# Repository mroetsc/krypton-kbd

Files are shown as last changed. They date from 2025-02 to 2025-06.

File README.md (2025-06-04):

# Krypton-KBD

Ergonmic split keyboard created with [ergogen](https://github.com/ergogen/ergogen).

Named after the noble gas [krypton](https://en.wikipedia.org/wiki/Krypton).

## Features
* Completely wireless with support for wired
* One rotary encoder per half
* Num row
* Ergonomic, easily reachable thumb cluster, also ideal for larger hands
* 3D-printed case (open and closed versions) and switchplate
* Support for [ZMK Studio](https://zmk.dev/docs/features/studio), allowing keymap changes without reflashing
* Support for nice!view displays

## Images
keyboard

# Build instructions
The build instructions can be found [here](https://github.com/mroetsc/krypton-kbd/blob/main/docs/build_instructions.md).

## Keymap
The default keymap is for Colemak-DH. It can easily be changed using [ZMK Studio](https://zmk.dev/docs/features/studio).
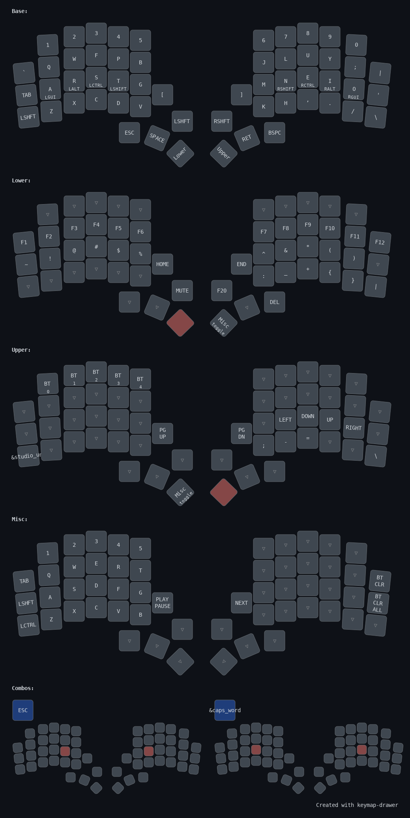
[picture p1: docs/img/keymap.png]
Keymap Drawing


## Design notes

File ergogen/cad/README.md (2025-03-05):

# CAD Model sources
## Rotary encoder
https://grabcad.com/library/ec11-rotary-encoder-with-switch-1 (modified colors)

## Encoder knob
https://grabcad.com/library/rotary-encoder-with-knop-1 (modified to only have knob)

## JST connector
https://grabcad.com/library/jst-ph-2-00mm-connector-set-1

## Kali hotswap socket
https://grabcad.com/library/kailh-hotswap-mx-1

## Nice!Nano
https://grabcad.com/library/nice-nano-v2-board-1 (modified colors)

## MX keycaps
https://grabcad.com/library/cherry-mx-keycaps-1 (cut out and modified color)

## MX switch
https://grabcad.com/library/kailh-polia-switch-cherry-mx-compatible-1 (modified colors)

## Nice!View
https://grabcad.com/library/nice-view-oled-1

## Power switch
https://tech.alpsalpine.com/e/products/detail/SSSS811101/ (modified colors)

## Reset switch
https://grabcad.com/library/panasonic_evqpuj_evqpua-1

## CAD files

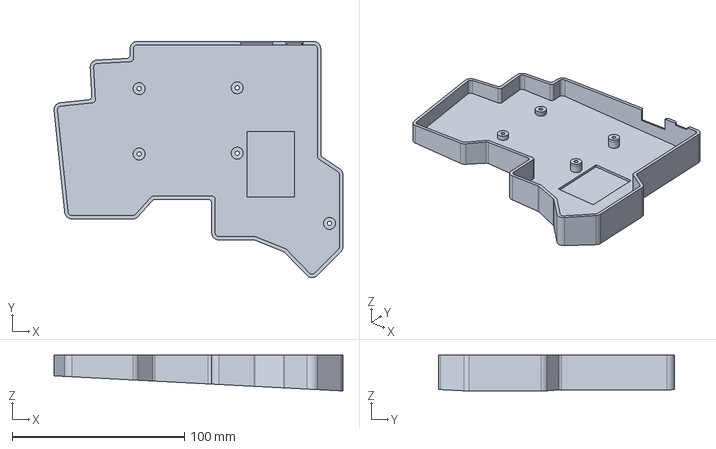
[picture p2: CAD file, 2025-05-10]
case/closed_case.FCStd
167.9 x 137.2 x 20.9 mm

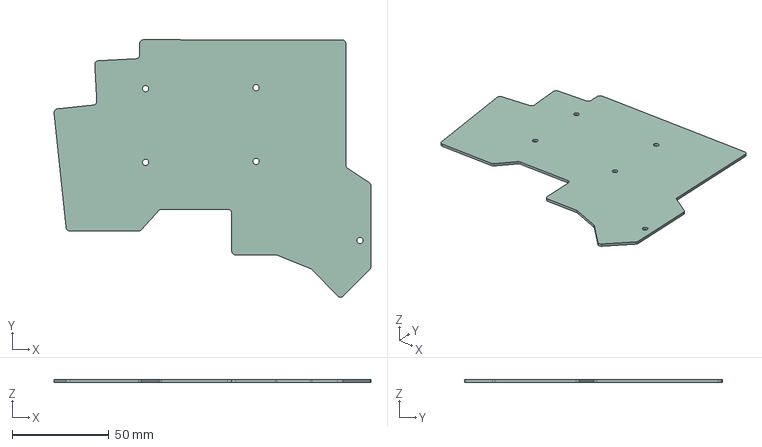
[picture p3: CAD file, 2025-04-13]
case/parts/pcb_left.step
163.5 x 132.8 x 1.51 mm

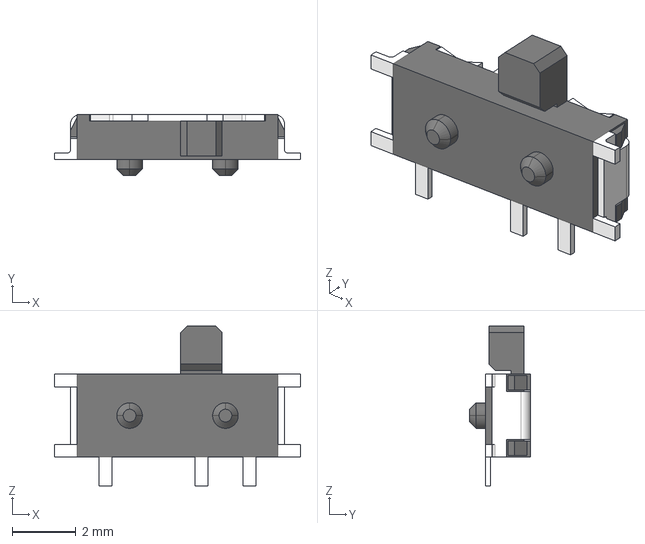
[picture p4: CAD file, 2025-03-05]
ergogen/cad/power_switch.stp
7.70 x 1.90 x 5.00 mm

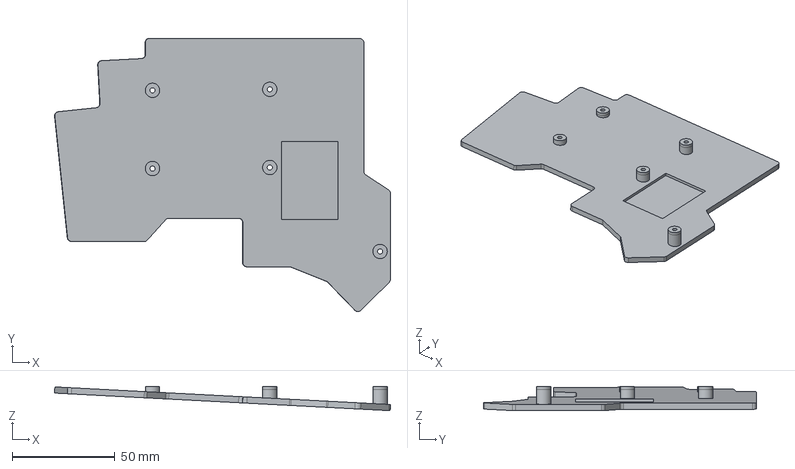
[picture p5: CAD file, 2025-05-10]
case/exports/open_case-left.step
163.3 x 132.8 x 11.8 mm

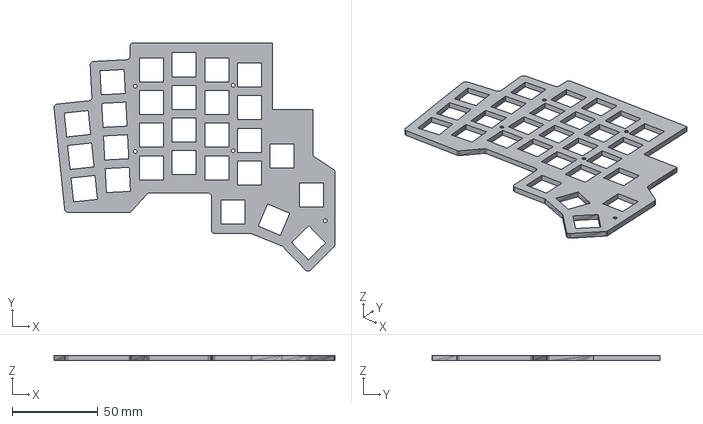
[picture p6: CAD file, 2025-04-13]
case/parts/switchplate_left.step
163.5 x 132.8 x 3.00 mm

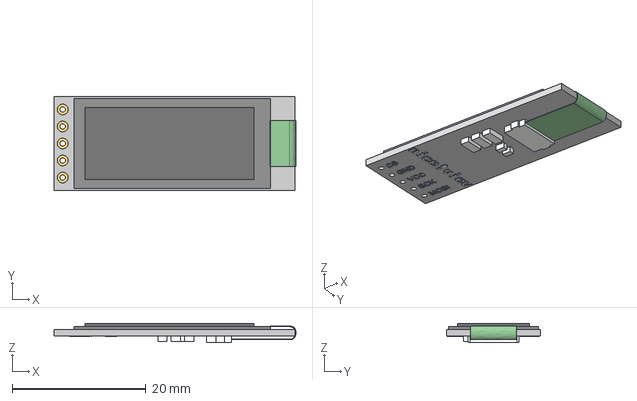
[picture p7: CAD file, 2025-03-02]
ergogen/cad/nice_view.step
36.1 x 14.0 x 2.90 mm

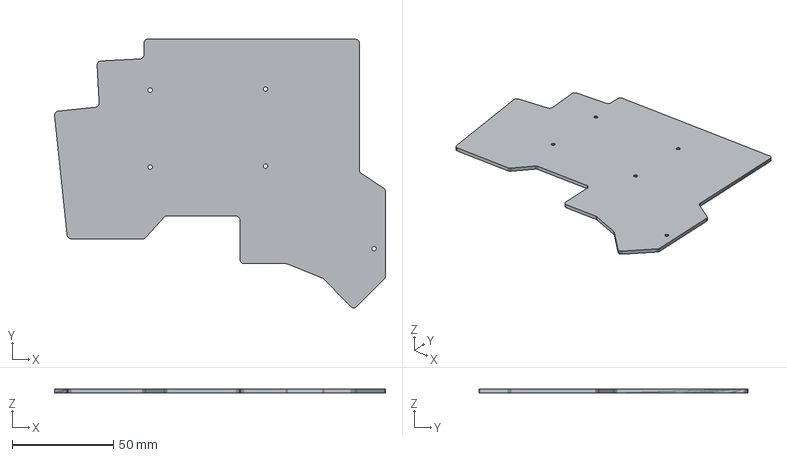
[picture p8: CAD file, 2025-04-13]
case/parts/bottom_left.step
163.5 x 132.8 x 2.00 mm

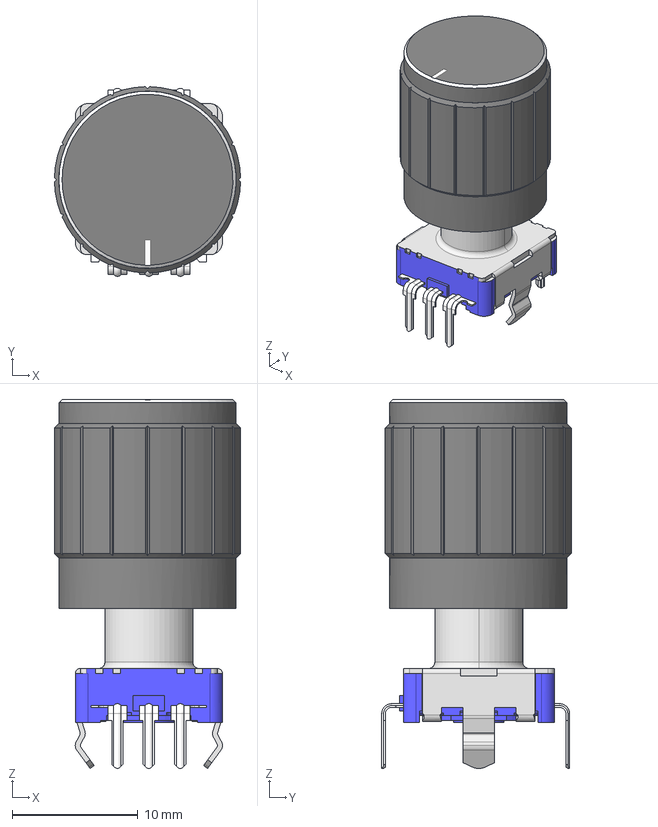
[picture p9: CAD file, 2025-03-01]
ergogen/cad/encoder_with_knob.step
14.8 x 15.1 x 29.3 mm
ÃÃ½ÃÂªÂ±Ã ÃÃ«ÃÃ·EC11E-05SW
Rotary Encoder - KY-040 v023

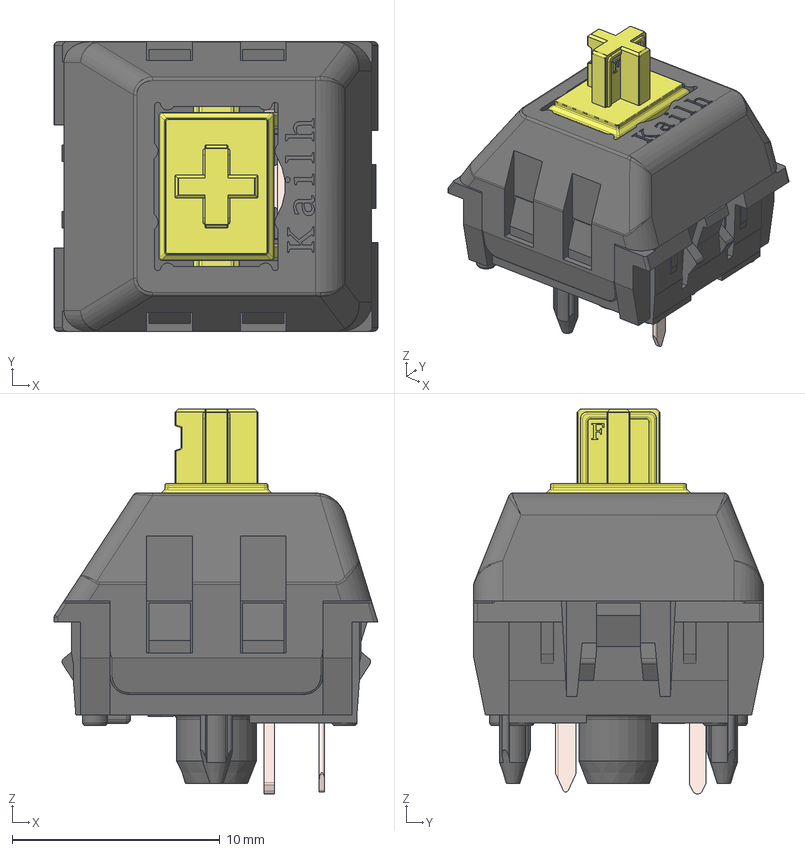
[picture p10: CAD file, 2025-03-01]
ergogen/cad/mx_switch.step
15.6 x 13.9 x 18.5 mm
Housing
ThickContact
SpringContact
Stem
Lid

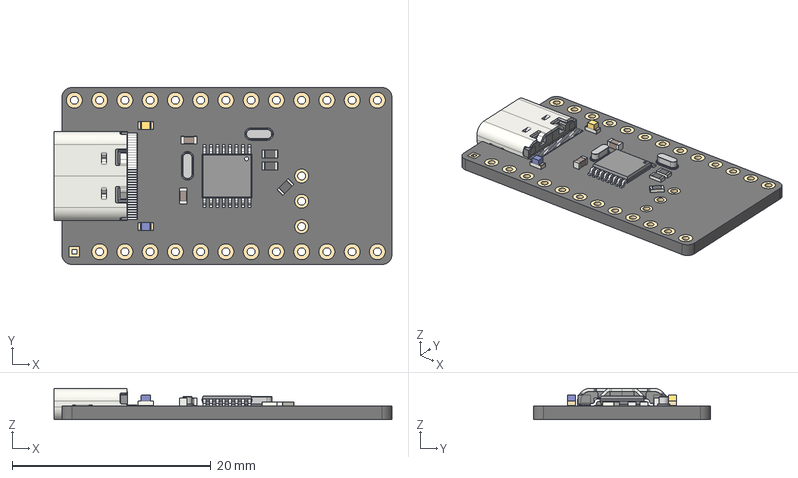
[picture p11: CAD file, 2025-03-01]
ergogen/cad/mcu_nice_nano.step
34.0 x 17.8 x 3.16 mm
nice!nano v1.0
nice!nano v1.001
nice!nano v1.002
nice!nano v1.003
nice!nano v1.004
nice!nano v1.005
nice!nano v1.006
nice!nano v1.007
nice!nano v1.008
nice!nano v1.009
nice!nano v1.010
nice!nano v1.011
nice!nano v1.012
nice!nano v1.013
nice!nano v1.014
nice!nano v1.015
nice!nano v1.016
nice!nano v1.017
nice!nano v1.018
nice!nano v1.019
nice!nano v1.020
nice!nano v1.021
nice!nano v1.022
nice!nano v1.023
nice!nano v1.024
nice!nano v1.025
nice!nano v1.026
nice!nano v1.027
nice!nano v1.028
nice!nano v1.029
nice!nano v1.030
nice!nano v1.031
nice!nano v1.032
nice!nano v1.033
nice!nano v1.034
nice!nano v1.035
nice!nano v1.036
nice!nano v1.037
nice!nano v1.038
nice!nano v1.039
nice!nano v1.040
nice!nano v1.041
nice!nano v1.042
nice!nano v1.043
nice!nano v1.044
nice!nano v1.045
nice!nano v1.046
nice!nano v1.047
nice!nano v1.048
nice!nano v1.049
nice!nano v1.050
nice!nano v1.051
nice!nano v1.052
nice!nano v1.053
nice!nano v1.054
nice!nano v1.055
nice!nano v1.056
nice!nano v1.057
nice!nano v1.058
nice!nano v1.059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

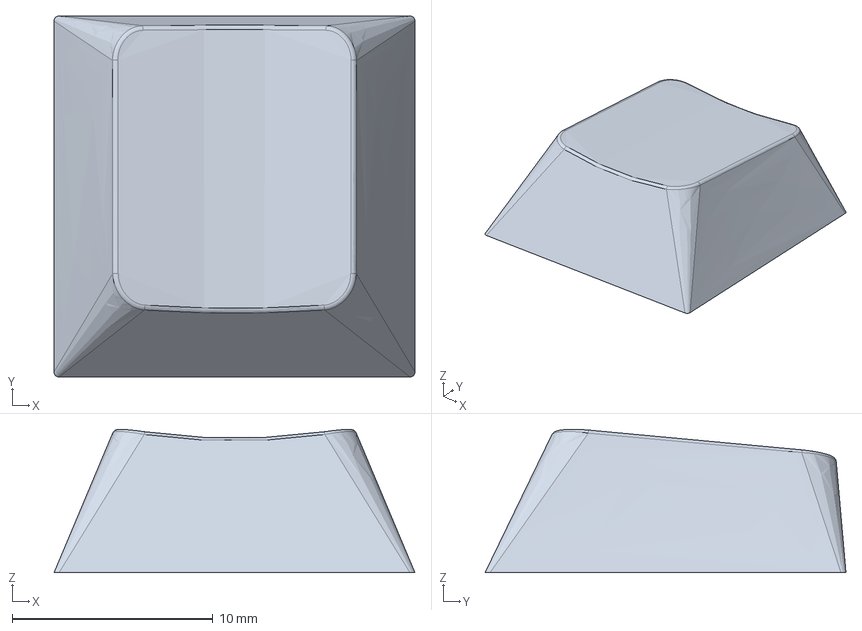
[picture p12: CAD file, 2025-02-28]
ergogen/cad/mx_keycap.step
18.0 x 18.0 x 7.15 mm

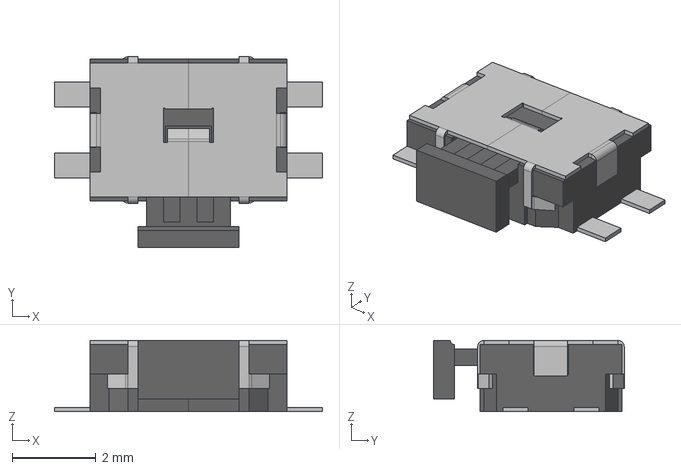
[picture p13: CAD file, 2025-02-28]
ergogen/cad/reset_switch.step
6.40 x 4.55 x 1.70 mm

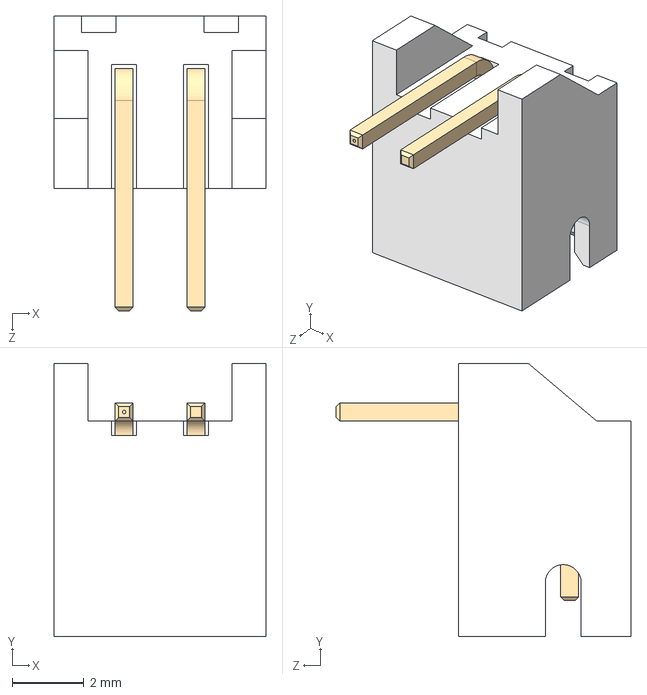
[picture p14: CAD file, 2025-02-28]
ergogen/cad/jst_connector.step
5.90 x 7.60 x 8.20 mm

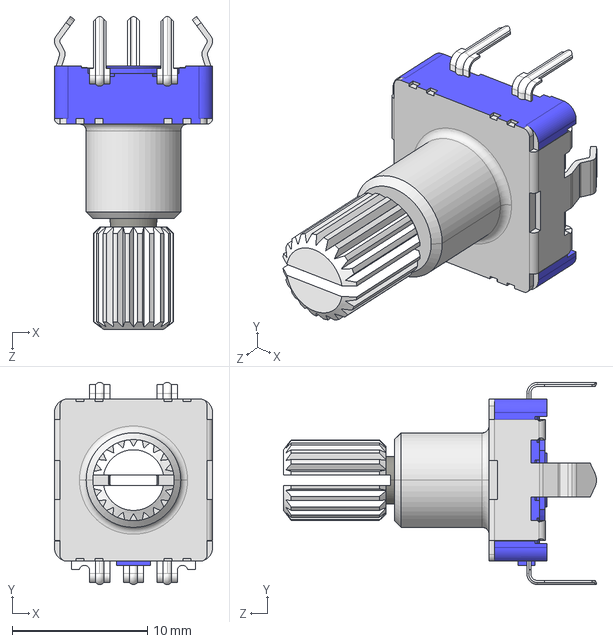
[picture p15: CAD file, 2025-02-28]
ergogen/cad/encoder.step
11.7 x 15.0 x 23.2 mm

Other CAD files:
case/exports/closed_case-left.step
case/open_case.FCStd
ergogen/cad/kali_hotswap.step
case/exports/switchplate-left.stl

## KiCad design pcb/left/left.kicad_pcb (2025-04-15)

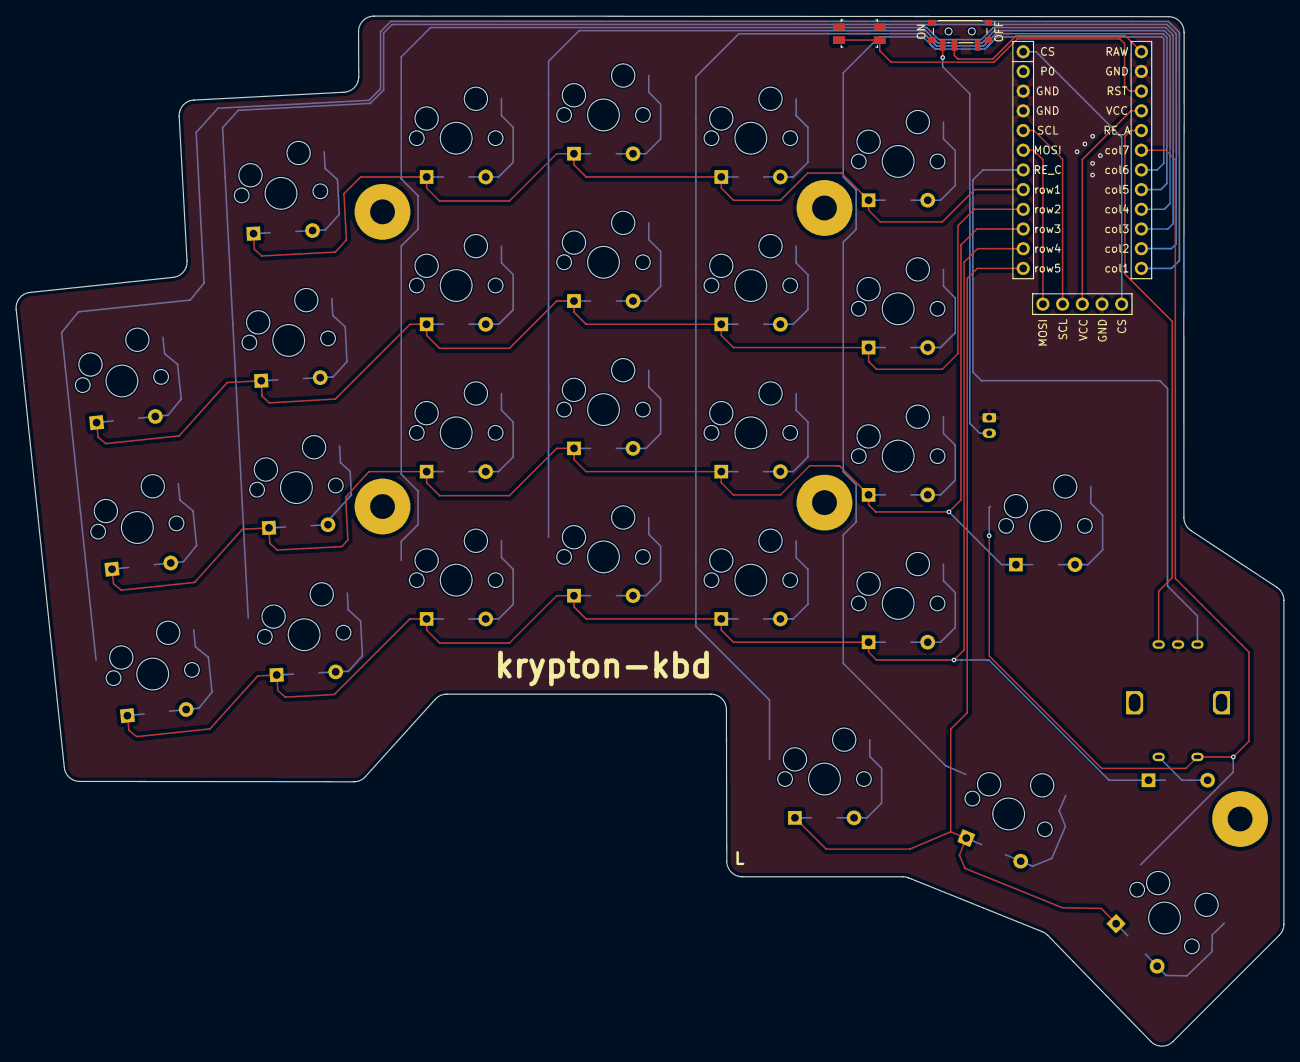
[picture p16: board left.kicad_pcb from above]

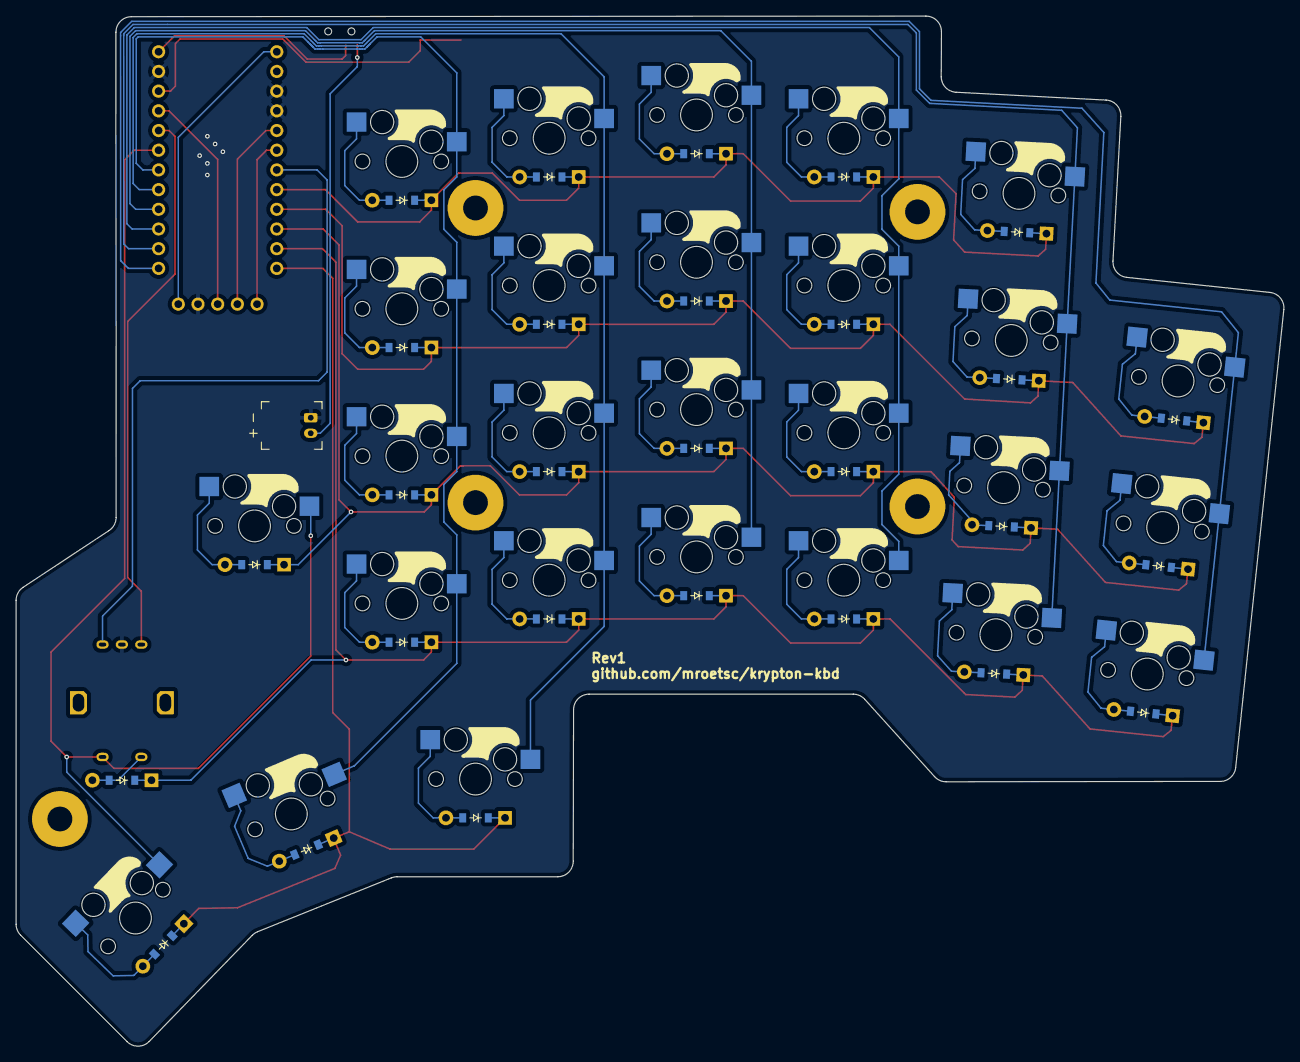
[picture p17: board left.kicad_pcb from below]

Board: 2 copper layers, 163.5 x 132.8 mm, 66 parts (56 on the bottom side), 50 nets.

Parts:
D1, D2, D3, D4, D5, D6, D7, D8, D9, D10, D11, D12, D13, D14, D15, D16, D17, D18, D19, D20, D21, D22, D23, D24, D25, D26, D27, D28: diode_tht_sod123
DISP1: display_nice_view
H1, H2, H3, H4, H5: mounting_hole_plated
JST1: battery_connector_jst_ph_2
MCU1: mcu_nice_nano
PWR1: power_switch_smd_side
RE1: rotary_encoder_ec11_ec12
RST1: reset_switch_smd_side
S1, S2, S3, S4, S5, S6, S7, S8, S9, S10, S11, S12, S13, S14, S15, S16, S17, S18, S19, S20, S21, S22, S23, S24, S25, S26, S27: switch_mx

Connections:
BAT_P: JST1.2, PWR1.3
CS: DISP1.5, MCU1.24
GND: DISP1.4, JST1.1, MCU1.2, MCU1.21, MCU1.22, RE1.B, RST1.1, RST1.3
MOSI: DISP1.1, MCU1.19
RAW: MCU1.1, PWR1.2
RE_A: MCU1.5, RE1.A
RE_C: MCU1.18, RE1.C
RST: MCU1.3, RST1.2, RST1.4
SCL: DISP1.2, MCU1.20
VCC: DISP1.3, MCU1.4
brackets_home: D24.2, S24.2
col1: MCU1.12, S1.1, S2.1, S3.1
col2: MCU1.11, S4.1, S5.1, S6.1, S7.1
col3: MCU1.10, S8.1, S9.1, S10.1, S11.1
col4: MCU1.9, S12.1, S13.1, S14.1, S15.1
col5: MCU1.8, S16.1, S17.1, S18.1, S19.1, S25.1
col6: MCU1.7, S20.1, S21.1, S22.1, S23.1, S26.1
col7: MCU1.6, RE1.S1, S24.1, S27.1
encoder_encoder: D28.2, RE1.S2
index_bottom: D16.2, S16.2
index_home: D17.2, S17.2
index_num: D19.2, S19.2
index_top: D18.2, S18.2
inner_bottom: D20.2, S20.2
inner_home: D21.2, S21.2
inner_num: D23.2, S23.2
inner_top: D22.2, S22.2
layer_cluster: D27.2, S27.2
middle_bottom: D12.2, S12.2
middle_home: D13.2, S13.2
middle_num: D15.2, S15.2
middle_top: D14.2, S14.2
pinky_bottom: D4.2, S4.2
pinky_home: D5.2, S5.2
pinky_num: D7.2, S7.2
pinky_top: D6.2, S6.2
ring_bottom: D8.2, S8.2
ring_home: D9.2, S9.2
ring_num: D11.2, S11.2
ring_top: D10.2, S10.2
row1: D7.1, D11.1, D15.1, D19.1, D23.1, MCU1.17
row2: D3.1, D6.1, D10.1, D14.1, D18.1, D22.1, MCU1.16
row3: D2.1, D5.1, D9.1, D13.1, D17.1, D21.1, D24.1, MCU1.15
row4: D1.1, D4.1, D8.1, D12.1, D16.1, D20.1, D28.1, MCU1.14
row5: D25.1, D26.1, D27.1, MCU1.13
space_cluster: D26.2, S26.2
stretch_bottom: D1.2, S1.2
stretch_home: D2.2, S2.2
stretch_top: D3.2, S3.2
super_cluster: D25.2, S25.2

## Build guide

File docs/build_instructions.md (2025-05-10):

# Build instructions

## BoM

### Parts to buy

| Name | Quantity | Suggested Seller / Where I got it |
|---|---|---|
| PCB* | 1 per side | [jlcbcb.com](https://jlcpcb.com/)  |
| nice!nano | 2 | [splitkb.com](https://splitkb.com/products/nice-nano?variant=39408154116173) |
| MillMax Low Profile Sockets | 2 | [splitkb.com](https://splitkb.com/products/mill-max-low-profile-sockets?variant=31945995845709) |
| Wireless Controller Expansion Bundle | 1 | [splitkb.com](https://splitkb.com/products/wireless-controller-expansion-bundle?_pos=2&_sid=110e7f3c6&_ss=r) |
| Kalih Hotswap Sockets (MX) | 2 | [splitkb.com](https://splitkb.com/products/kailh-hotswap-sockets?_pos=2&_sid=0bcba2286&_ss=r) |
| SMD Diodes | 1 | [splitkb.com](https://splitkb.com/products/smd-diodes?variant=42283984027907) |
| EC11 Rotary Encoder | 2 | [keycapsss.com](https://keycapsss.com/Rotary-Encoder-with-switch-EC11/KC10028-FS) |
| Reset Switch EVQPUA02K | 2 | [mouser.de](https://www.mouser.de/ProductDetail/Panasonic/EVQ-PUA02K?qs=whhzBCqEXCvFsgipcL1tig%3D%3D) |
| Battery | 2 | - |
| M2x5 Screws | 1 | [splitkb.com](https://splitkb.com/products/m2-screws?variant=42396986999043) |
| M2x6 Brass Spacers | 1 | [splitkb.com](https://splitkb.com/products/brass-m2-spacers?variant=42396969140483) |
| Rubber Feet Bumpons | 1 | [keycapsss.com](https://keycapsss.com/Rubber-Feet-Bumpons/KC10108-15x2-BK) |
| Encoder Knobs (optional) | 2 | - |
\* The gerber files can be found [here](https://github.com/mroetsc/krypton-kbd/blob/main/pcb/left/gerber/left-gerber.zip) and [here](https://github.com/mroetsc/krypton-kbd/blob/main/pcb/right/gerber/right-gerber.zip) (left and right).

### Parts to print
You can choose between an open case and a closed case. The open case does not have walls, as seen on the image in the Readme.

| Name | Quantity | File path |
|---|---|---|
| Switchplate Left | 1 | [Link](https://github.com/mroetsc/krypton-kbd/blob/main/case/exports/switchplate-left.stl) |
| Switchplate Right | 1 | mirror in slicer |
| Case Left | 1 | [Open](https://github.com/mroetsc/krypton-kbd/blob/main/case/exports/open_case-left.step) OR [Closed](https://github.com/mroetsc/krypton-kbd/blob/main/case/exports/closed_case-left.step) |
| Case Right | 1 | mirror in slicer |

## Assembly
You will need some soldering skills to complete the assemply. Take your time, especially for the SMD components.
Because the overall assemply of the case and the board is inspired by the [splitkb Aurora Lily58](https://splitkb.com/products/aurora-lily58), the build guide is similiar. Each step has a short description here and a link to the relevant splitkb docs page. See this page for good images and a detailed description.

### Diodes
Start by putting some solder on one side of the diode pads. Heat the solder again and carefully push the diode in. Note the correct orientation. Then add solder on the other side. Don't forget the diode on the encoder.
> [splitkb page](https://docs.splitkb.com/product-guides/aurora-series/build-guide/diodes) 

### Switch sockets
Place the sockets into the holes and add solder. Make sure the sockets sits correctly on the PCB.
> [splitkb page](https://docs.splitkb.com/product-guides/aurora-series/build-guide/switch-sockets) 

### Power switches
Use the same technique as on the diodes, put some soledr on one pad and then push the switch in. It should also work to just drop the switch into location and solder then, since it has two pins for orientation.
> [splitkb page](https://docs.splitkb.com/product-guides/aurora-series/build-guide/power-switch) 

### Reset buttons
Pretty much the same as power switches. Locate the footprint on the upper side and solder it in.
No splitkb link, since they are using THT buttons.

### JST jacks
Place the jack into the corresponding place and solder one pin. Make sure it sits straight and solder the other pin. They need to go on the back side of the PCB where the markings for plus and minus are.
> [splitkb page](https://docs.splitkb.com/product-guides/aurora-series/build-guide/jst-jacks) 

### Optional: Display sockets
This only applies if you are installing nice!view display. Locate the correct spot on the upper side and solder the sockets in. Check if it sits straight after the first pin.
> [splitkb page](https://docs.splitkb.com/product-guides/aurora-series/build-guide/oled-sockets) 

### Microcontrollers
Place the sockets into the correct spot on the front and solder the pins. Check if it sits straight after the first pin. Then put the pins in slightly and push them down with the MCU. Solder everything there.
> [splitkb page](https://docs.splitkb.com/product-guides/aurora-series/build-guide/microcontrollers) 

### Batteries
Check the polarity of your battery, and if the JST plug is in the correct orientation before plugging the battery in. If you still need to install JST plugs, splitkb has some more infos. You can then later secure your battery in the bottom of the case.
> [splitkb page](https://docs.splitkb.com/product-guides/aurora-series/build-guide/batteries) 

### Rotary Encoders
Place the encoders into the PCB and solder the legs. Make sure you haven't bent any legs while installing. You can use plenty of solder for the big pins, as they are holding it in mechanically.
> [splitkb page](https://docs.splitkb.com/product-guides/aurora-series/build-guide/rotary-encoders) 

### Switches
Start by screwing the brass spacers into the switchplate from the top. Then put some switches into the opposing edges, always make sure the switches have no bent pins. You could also insert all switches into the switchplate first, this could prevent some difficulties with installing the switches after sliding the plate on the PCB.
Gently insert the switchplate into the PCB and make sure it aligns. If not done already, insert the remaining switches.
> [splitkb page](https://docs.splitkb.com/product-guides/aurora-series/build-guide/switches) 

### Case
Align the case standoffs with the brass spacers that stick through the PCB. Secure the battery in the mold in the bottom of the case and then plug it in in the correct orientation / polarity. Then screw in the remaining screws from the bottom to secure the whole assemply.

## Flashing the firmware
Plug the nice!nano into your PC. It should show up as storage device if this is the first time booting up. Power needs to be switched on for this. If it does not appear, push the reset button twice in quick succession, which will place the nice!nano into bootloader mode. This is also helpful when reflashing another firmware.
Place the firmware `.uf2` files in the directory that opens. You can get the firmware files [here](https://github.com/mroetsc/krypton-zmk-config/releases/latest/). Scroll down to the assets and download the `.uf2` files. Make sure you put the correct file on the correct side.
> [splitkb page](https://docs.splitkb.com/product-guides/nice-nano/flashing)

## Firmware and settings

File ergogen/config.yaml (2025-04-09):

meta:
  engine: 4.1.0
  name: krypton
  version: alpha
  ref: &kb_ref "alpha release"
  author: mroetsc
  url: &kb_url github.com/mroetsc/krypton-kbd

units:
  # --- Proxy Spacing Variables --- #
  kx: u
  ky: u

  switch_cutout: 14
  # TODO: double check the value
  encoder_cutout: 14
  screw_diameter: 2.2

  # --- Padding Variables --- #
  padding: 2
  px: kx + padding
  py: ky + padding
  dpx: px + 2 * padding
  dpy: py + 2 * padding

  # --- Other --- #
  stagger: 3
  splay: -3
  extra_spacing: 1
  thumbsplay: -23

  # --- Components --- #
  encoder_width: 12
  encoder_height: 12
  mcu_width: 18
  mcu_height: 33
  display_height: 36
  display_width: 14

points:
  zones:
    # ----- Keys ----- #
    matrix:
      anchor:
        shift: [50, -175]
        rotate: -2splay
      key:
        tags: [switch]
        padding: 1ky
        spread: 1kx
      columns:
        stretch:
          key:
            column_net: col1
          rows:
            num.skip: true
        pinky:
          key:
            stagger: stagger
            spread: 1.05ky
            splay: splay
            column_net: col2
        ring:
          key:
            stagger: 2stagger
            spread: 1.05ky
            splay: splay
            column_net: col3
        middle:
          key:
            stagger: stagger
            column_net: col4
        index:
          key:
            stagger: -stagger
            column_net: col5
        inner:
          key:
            stagger: -stagger
            column_net: col6
        brackets:
          key:
            stagger: -3stagger
            column_net: col7
          rows:
            bottom.skip: true
            top.skip: true
            num.skip: true
      rows:
        bottom:
          row_net: row4
        home:
          row_net: row3
        top:
          row_net: row2
        num:
          row_net: row1

    thumb:
      anchor:
        ref: matrix_index_bottom
        shift: [0.5kx, -1.35ky]
      key:
        tags: [switch]
        padding: 1ky
        spread: 1ky
      columns:
        super:
          key:
            column_net: col5
        space:
          key:
            splay: thumbsplay
            spread: 1.25kx
            stagger: -1.5stagger
            column_net: col6

        layer:
          key:
            splay: thumbsplay
            spread: 1.25kx
            stagger: -1.5stagger
            column_net: col7
      rows:
        cluster:
          row_net: row5

    encoder:
      anchor:
        ref: matrix_brackets_bottom
        shift: [0.9kx, -0.2ky]
      key:
        tags: [encoder]
        width: encoder_width
        height: encoder_height
      columns:
        encoder:
          key:
            column_net: col7
      rows:
        encoder:
          row_net: row4

    mcu:
      anchor:
        ref: matrix_brackets_top
        shift: [0.25kx, 1.55ky]
      key:
        width: mcu_width
        height: mcu_height

    display:
      anchor:
        ref: mcu
        shift: [0, -0.15py]
      key:
        width: display_width
        height: display_height

  mirror:
    ref: matrix_brackets_top
    distance: 100

outlines:
  _keys:
    - what: rectangle
      where: switch
      bound: false
      size: [switch_cutout, switch_cutout]

  _mcu:
    - what: rectangle
      where: mcu
      size: [mcu_width, mcu_height]

  _mcu_cutout:
    - what: rectangle
      where:
        ref: mcu
        shift: [1.75, 0]
      size: [mcu_width + 6, mcu_height + 10]

  _display:
    - what: rectangle
      where: display
      size: [display_width, display_height]

  _encoder:
    - what: rectangle
      where: encoder
      size: [encoder_width, encoder_height]

  _encoder_cutout:
    - what: rectangle
      where: encoder
      size: [encoder_cutout, encoder_cutout]

  _components:
    - name: _components
    - operation: add
      name: _keys
    - operation: add
      name: _mcu
    - operation: add
      name: _display
    - operation: add
      name: _encoder
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

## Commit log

2024-11-21 feat(points): Added oled and encoder
2024-11-23 feat(pcb): testing pcb with first draft
2025-02-10 chore: added ceolide footprints as submodule
2025-02-11 feat: began rework
    did rough points
    [config.yaml]
2025-02-23 feat: started with pcb
2025-02-25 feat: Added more footprints
2025-02-26 Modified nets on nice nano and encoder
2025-02-26 Shoulve fixed nets for encoder
    [config.yaml]
2025-02-28 Switched footprints to ceoloide and added 3d models
    [encoder.step, jst_connector.step, kali_hotswap.step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]
2025-03-01 Fixed colors of switches and nice nano 3d models
    [mcu_nice_nano.step, mx_switch.step, power_switch.stp]
2025-03-01 Edited reset and power switch footprints to match new outlines
    [config.yaml]
2025-03-01 Added conversion of jscad to stl to watcher script
2025-03-01 Added encoder with knob cad file
    [encoder_with_knob.step]
2025-03-01 Added simple case to test layout
2025-03-02 Added option for nice view
    [nice_view.step]
2025-03-02 Moved nice nano and power switch closer to edge
2025-03-03 Moved battery connector a bit
2025-03-04 Added mounting holes
2025-03-04 Began work with case
2025-03-05 Updated ceoloide footprints submodule to latest ref
2025-03-05 Changed dir structure
    [left_routing_test.kicad_pcb]
2025-03-05 Added switchplate and mounting holes, changed how case will be created
    only creating switchplate and bottom area with ergogen, rest in freecad
2025-03-05 Added cad sources and fixed power switch colors
    [power_switch.stp]
2025-03-06 Added encoder cutout to switchplate
2025-03-07 Changed encoder row net and fixed net for right side
    [config.yaml]
2025-03-09 Added kicad and freecad gitignore
2025-03-09 Began with case files
2025-03-09 Fixed outer right mounting hole misalignment and changed switchplate and bottom thickness
    [config.yaml]
2025-03-09 Imported models into case
2025-03-10 Finished preliminary routing for left side
    [left.kicad_pcb]
2025-03-11 Minor adjustments to pcb routing
    [left.kicad_pcb]
2025-03-13 Added note about ec11 footprint
2025-04-06 Chaged pcb dir structure
    [left.kicad_pcb]
2025-04-06 Redid left routing
    [left.kicad_pcb]
2025-04-06 Finished routing for right side
    [right.kicad_pcb]
2025-04-06 Added proper sheet names
    [left.kicad_pcb, right.kicad_pcb]
2025-04-06 Set gerber and drill output dir
    [left.kicad_pcb, right.kicad_pcb]
2025-04-07 Added cutout for mcu to switchplate
2025-04-07 Restructured case dir
    [bottom_left.step, case.FCStd, pcb_left.step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]
2025-04-07 Fixed pcb hole diameter and bottom plate screws
    [config.yaml]
2025-04-08 wip: rough case alignments
    [case.FCStd, pcb_left.step]
2025-04-09 Fixed mounting hole diameter and position
    top and bottom right mounting hole was too small for standoff and in the
    way of the pad once adjusted; also increased pad size to match 3d
    printed standoff from bottom
    [config.yaml]
2025-04-09 Refined pcb routing, fixed hole issue on pcb
    [left.kicad_pcb, right.kicad_pcb]
2025-04-09 Generated production files
    [left-B_Cu.gbr, left-B_Mask.gbr, left-B_Paste.gbr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]
2025-04-13 Updated base models for case
    [bottom_left.step, pcb_left.step, switchplate_left.step]
2025-04-15 Finished rough shape of case bottom
    [case.FCStd]
2025-04-15 Adjusted nice nano model height in pcb
    [left.kicad_pcb]
2025-04-16 Started with case io cutouts
    [case.FCStd]
2025-04-23 Created case without outer walls
    [case_without_walls.FCStd]
2025-04-28 Changed bottom plate to 3mm and reduced space between plate and PCB on case without walls
    [case_without_walls.FCStd]
2025-04-28 Added bumper mounting guides to open case
    [case_without_walls.FCStd]
2025-04-28 Renamed case files
    [case.FCStd, case_without_walls.FCStd, closed_case.FCStd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]
2025-04-29 Changed bottom plate to 3mm on closed case
    [closed_case.FCStd]
2025-04-29 Added io cutouts to closed case
    [closed_case.FCStd]
2025-04-29 Added bumper mounting guide to closed case
    [closed_case.FCStd]
2025-04-30 Adjusted freecad model outlines
    [closed_case.FCStd, open_case.FCStd]
2025-04-30 Added pocket for easier battery mounting to cases
    [closed_case.FCStd, open_case.FCStd]
2025-05-10 Added exported case files
    [closed_case-left.step, closed_case.FCStd, open_case-left.step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]
2025-06-04 Fixed typo and added better case description in README
